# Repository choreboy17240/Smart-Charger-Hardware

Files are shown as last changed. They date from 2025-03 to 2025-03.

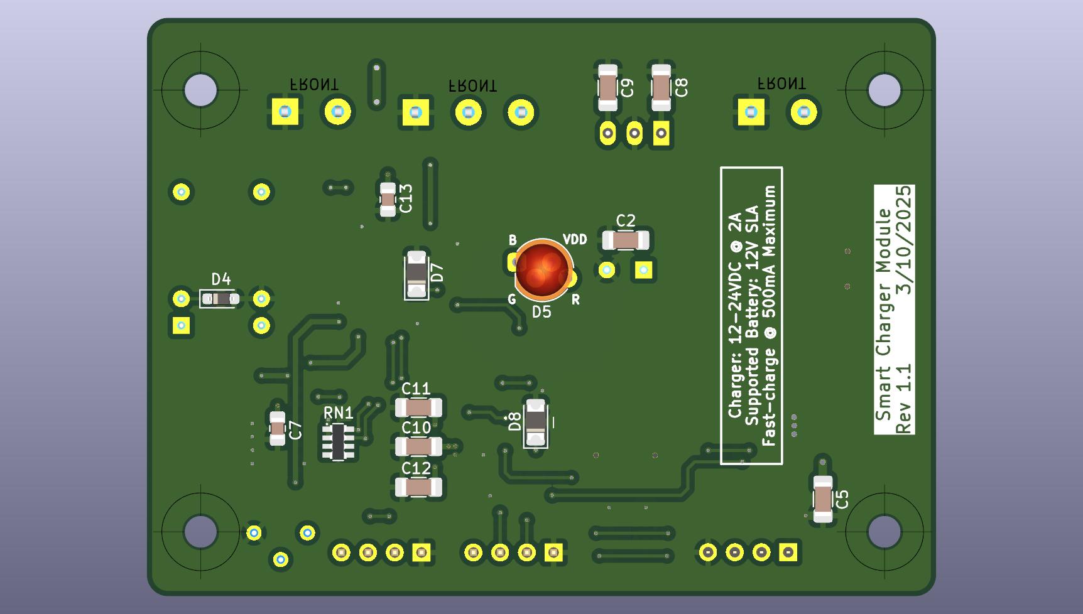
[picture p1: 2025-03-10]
Images/Smart Charger PWB Assembly Bottom v1.1 20250310.jpg

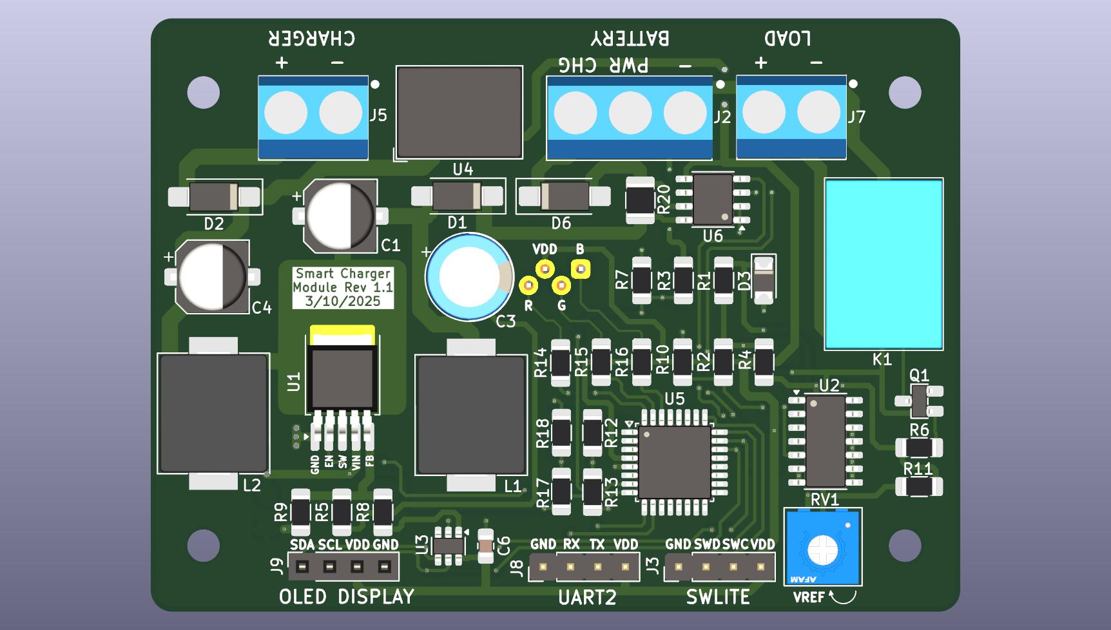
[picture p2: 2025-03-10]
Images/Smart Charger PWB Assembly Top v1.1 20250310.jpg

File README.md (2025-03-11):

# Battery On-Board Charger

## Overview

This repository contains the design files for a Battery On-Board Charger, a DC-DC converter
designed to safely charge sealed lead-acid (SLA) batteries from external power sources. The 
system operates as a buck-boost converter with intelligent microcontroller control for charge
management.

Please see the accompanying software repository on GitHub for an example Arduino STM32 
application that can be built under PlatformIO and used to program the on-board STM32 micro
using an ST-Link programmer.  Programming is done using a custom"SWD-Lite" interface that I 
use for compact, low-cost projects.  SWD-Lite uses a standard 1x4 2.54mm male header to 
provide the absolute minimum number of signals needed or the ST-Link programmer to operate.

I'm sharing this design information and the associated software in hopes that others might 
find it interesting or helpful. It's a hobby project for me, so your mileage may vary!

This is my first attempt to share a KiCad (v9.0) project, so I'd be interested to hear
about whether there are issues or not.  I've exported the global custom symbols and footprints
that I used in the design, so hopefully this should be a standalone PWB design.

## Hardware Specifications

#### Battery Charging
- **Input Voltage**: 12-24V DC
- **Output Voltage**: Adjustable (typically 12V-15.5V for lead-acid batteries)
- **Maximum Charge Current**: 500-600mA
- **Controller**: STM32G030K8T6 (64KB Flash, 8KB RAM)
- **Power Stage**: XL6008 DC-DC converter (Buck-Boost topology)
- **Current Sensing**: INA219 I2C sensor
- **Voltage Control**: MCP4726A0 I2C DAC
- **Status Indicator**: RGB LED
- **Interfaces**: UART, I2C, SWD programming port
- **Operating Temperature**: Room temp

#### Battery Undervoltage Protection 
- **Low-Voltage Cutout**: Adjustable limit (trim pot)

## Key Features

- Software-adjustable charge voltage via I2C DAC
- Real-time current and voltage monitoring
- Temperature-compensated charging profiles
- Multi-stage charging (bulk, absorption, float)
- Status indication via RGB LED
- UART interface for diagnostics and monitoring
- Surge and reverse polarity protection
- Thermal management and over-current protection

## Power Conversion Design

The design utilizes an XL6008 DC-DC converter configured in a buck-boost topology:
- Input filtering through hybrid aluminum capacitors
- High-efficiency power inductors (47µH Sunlord MWSA1004S)
- Schottky diode rectification (B360AE)
- High-quality output filtering with polymer capacitors
- Feedback network with DAC-controlled reference voltage

## PCB Design Considerations

- 2-layer PCB with optimized (kinda) thermal design
- Ground plane for noise reduction and thermal dissipation
- Separate analog and digital ground regions
- Thermal management for XL6008 regulator
- EMI/EMC design practices for switching converter
- Power and signal path optimization

## Undervoltage Protection Circuit

The design incorporates a hardware-based undervoltage protection circuit
to prevent battery damage while under load:

- **Components**:
  - LM339 Quad Comparator for voltage threshold detection
  - MMBT3906 PNP transistor (Q1) for relay driver
  - NS_SRS_SPDT relay (K1) for power disconnection
  - Precision resistor divider network for voltage sensing

- **Operation**:
  - Continuously monitors the battery voltage through a resistive divider
  - When battery voltage falls below a preset threshold (adjustable via the
    RV1 trim pot)
  - Comparator triggers, driving the PNP transistor into conduction
  - Relay energizes, disconnecting the load from the battery
  - Hysteresis provided by R11 (1MΩ) prevents oscillation at threshold
  - D4 provides flyback protection for relay coil

- **Benefits**:
  - Prevents deep discharge of batteries
  - Hardware-based protection operates independently of microcontroller
  - Adjustable threshold for different battery types
  - Fast response time for critical undervoltage conditions
  - Failsafe design ensures load disconnection on power loss

The circuit provides essential protection for battery-powered systems, preventing
damage from excessive discharge while allowing normal operation above the safe 
voltage threshold.

**Note:** As battery voltage limits vary across manufacturers and also depend
on how aggressive you want to be in draining the battery, you will need to 
adjust the RV1 trim potentiometer so that the shutoff occurs at the desired 
voltage. Typical range might be around 11.0-11.5 volts, but check the manufacturer's
recommendation for your battery!

## Thermal Performance

The design has been thermally optimized for enclosed operation:
- Maximum regulator temperature: ~52°C (125°F) at 600mA continuous charging
- Thermal steady state reached after ~30 minutes of operation
- Heat-generating components spaced for optimal thermal dissipation
- Current limited to 600mA for reliability in enclosed environments
- Charging current is constrained by the small heat sink are available for the 
  XL6008 converter, driven by the small packaging space availabe in my project.
- Control software limits the maximum current to that range automatically, but
  this is configurable.
- Redesign the PWB to increase the heat sink area or add a glue-on heat sink
  to the XL6008 if you want higher charging current.

## Usage Notes

See the system connection diagram in the `System` folder for details on how
to connect the module for charging and powering a load from the SLA battery.
The DPDT center-off switch allows the user to select between the following
operating modes:
1. `Charge`: Standby mode with the load off and battery being charged
2. `Power`: Active mode with the load on and charger disconnected
3. `Off`: Shuts down the system completely (no charging, no power to load)

The system should nomrally be left in the `Charge` mode, as the smart charger
is designed to charge up the battery and then automatically shift to a 
standby mode for a software configurable period (default is one week) to 
avoid overcharging the battery.

Charging the battery:
1. Switch the DPDT switch to the `Charge`position
2. The charger automatically determines charge state and applies appropriate charging profile
3. RGB LED color and flashing rate indicates charging status:
   - Blue (fast): Fast bulk charging
   - Yellow (medium): Absorption charging
   - Green (slow): Float/maintenance charging
   - Green (short keep-alive pulse every second): Standby mode
4. Once the battery is charged sufficiently, the charger will enter the standby
   state until it's time to top-off the battery.
   
Using the battery to power a load:
1. Switch the DPDT switch to the `Power` position
2. Battery protection circuit will automatically shut-off the load if battery
   voltage drops below the adjustable threshold.

## Software Configuration

The STM32G030 microcontroller requires appropriate firmware to control the charging process:
- Voltage setpoint control via MCP4726A0 DAC
- Current and voltage monitoring via INA219
- Temperature compensation
- Charging state machine
- Safety monitoring

See the companion firmware repository for microcontroller code.

## Limitations

- Maximum continuous charging current limited to 600mA for thermal management
- Not suitable for high-current applications without additional cooling
- Designed for lead-acid batteries (AGM, Gel, Flooded)
- Requires appropriate firmware for operation

## License

MIT open-source license - see the LICENSE file for details.

## Revision History

- 1.0: Initial design released to JLCPCB for prototype boards
- 1.1: Minor updates for silkscreen fixes

## Contact

Email: choreboy17240@gmail.com

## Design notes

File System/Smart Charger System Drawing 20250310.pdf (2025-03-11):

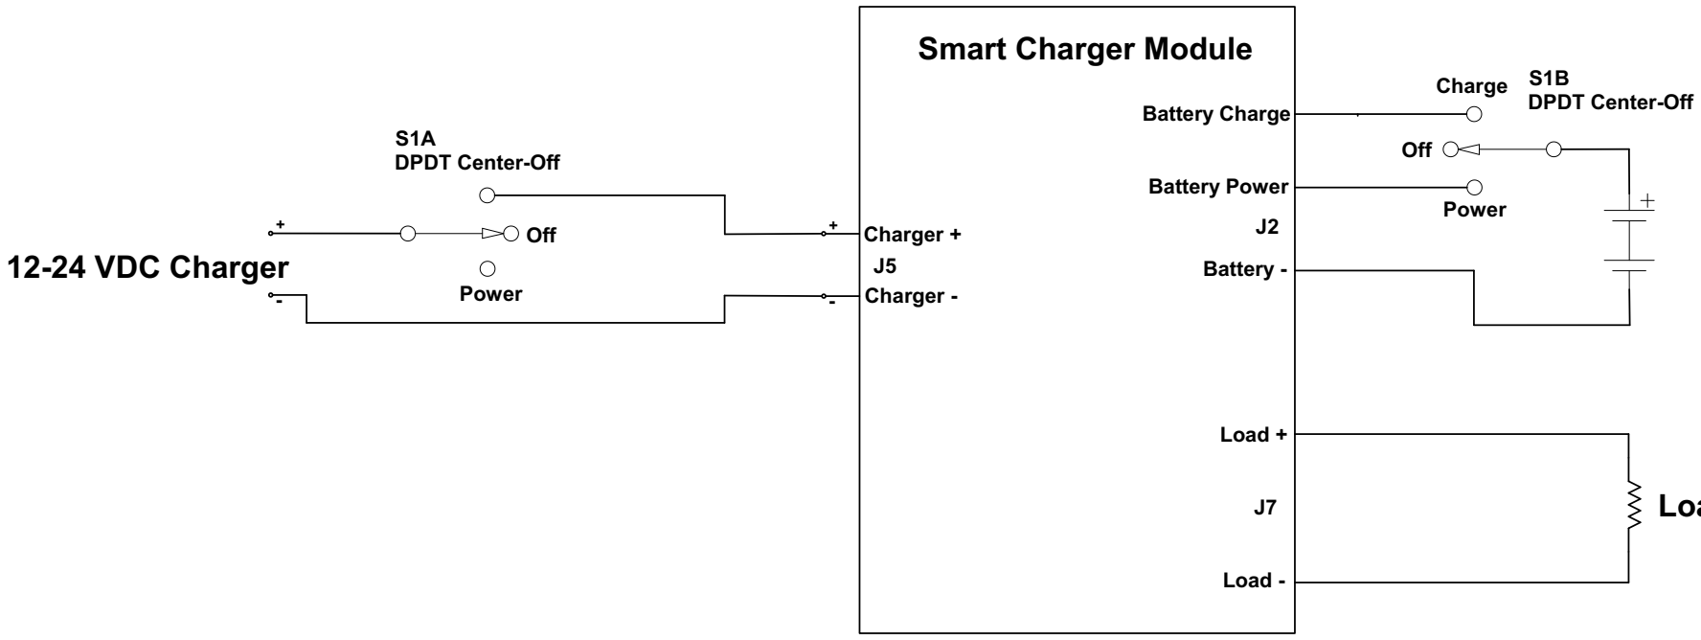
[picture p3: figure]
- - 12-24 VDC Charger; Charger +; Battery Charge; Charger -; Battery Power; Battery -; Load + Load - J7; Smart Charger Module; Charge; Power; Off; S1A DPDT Center-Off; S1B DPDT Center-Off

## Load

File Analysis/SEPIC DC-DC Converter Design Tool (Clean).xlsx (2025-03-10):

SEPIC DC:DC Convertor Design Tool
Design Parameters
VIN (MIN) | 12.0 | Volts
VIN (MAX) | 24.0 | Volts
VOUT (MIN) | 10.0 | Volts
VOUT (MAX) | 15.0 | Volts
VOUT Ripple Voltage | 0.1 | Volts
VD | 0.5 | Volts | B360, 2 Amp, 25C
IOUT (MAX) | 1.0 | Amps
Switching frequency | 400000 | Hz
Cs Value | 22 | uF
1. Duty cycle calculation
Duty cycle (MAX) | 68.9%
Duty cycle (MIN) | 26.6%
2. Inductor selection
L1 Ripple current (worst-case) | 0.5 | Amps
Targeted inductance (L1 = L2) | 4.133333333e-05 | Henry
 | 41.3 | uH
 | 0.04 | mH
L1 peak current | 1.55 | Amps
L2 peak current | 1.20 | Amps
3. Power MOSFET selection
MOSFET peak current | 2.75 | Amps
MOSFET RMS current | 1.72 | Amps
MOSFET voltage (MIN) | 39 | Volts
4. Output Diode Selection
Diode reverse voltage (MIN) | 39.00 | Volts
Diode average current | 1.00 | Amps
5. Coupling Capacitor Selection
Capacitor RMS current | 1.14 | Amps
Capacitor ripple voltage | 0.08 | Volts
6. Output Capacitor Selection
Capacitor RMS current | 1.14 | Amps
ESR (MAX) | 18.2 | mOhms
COUT (MIN) | 34.44444444 | uF
7. Input Capacitor Selection
Capacitor RMS current | 0.14 | Amps

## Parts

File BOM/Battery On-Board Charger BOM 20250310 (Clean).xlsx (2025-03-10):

Battery On-Board Charger Project |  |  |  |  |  |  |  | Revision: 03/10/2025
Reference | Qty | Value | Supplier | Supplier P/N | Manufacturer | Mfr P/N | Description | Comments
C1 | 1 | 22uF/63V | LCSC | C7472372 | NCC | HHXB630ARA220MF80G | Hybrid Al Capacitor SMD D6.3xL7.7mm 22uF 63V 1.5A@100kHz | N/A
C2,C5 | 2 | 1uF/50V | LCSC | C444884 | Samsung | CL31A105KB9LNNC | MLCC Capacitor SMD 1206 1uF 50V X5R | Also available from Digikey
C3 | 1 | 220uF/25V | LCSC | C133440 | NCC | APSG250ELL221MHB5S | Solid Al Capacitor Radial D8xP3.5xL11.5mm 220uF 25V 4.65A@100kHz | N/A
C4 | 1 | 47uF/50V | LCSC | C445256 | Nichicon | UUD1H470MCL1GS | Al Electrolytic Capacitor SMD D6.3xL7.7mm 47uF 50V 230mA@10kHz | N/A
C6,C7,C13 | 3 | 0.1uF/50V | LCSC | C49678 | Yageo | CC0805KRX7R9BB104 | MLCC Capacitor SMD 0805 0.1uF 50V X7R
C8,C9 | 2 | 10uF/50V | LCSC | C89632 | Samsung | CL31B106KBHNNNE | MLCC Capacitor SMD 1206 10uF 50V X7R | Replaces X5R version CL31A106MBHNNNE, also available from Digikey
C10,C12 | 2 | 0.1uF/25V | LCSC | C527347 | Yageo | CC1206KRX7R8BB104 | MLCC Capacitor SMD 1206 0.1uF 25V X7R
C11 | 1 | 4.7uF/50V | LCSC | C51205 | Samsung | CL31B475KBHNNNE | MLCC Capacitor SMD 1206 4.7uF 50V X7R | Also available from Digikey
D1,D2,D6 | 3 | B360AE | LCSC | C412514 | Diodes Inc | B360AE-13 | Schottky Diode SMD SMA 3A 60V Low-Leakage | N/A
D3,D7,D8 | 3 | 3.3V | LCSC | C235771 | On Semi | MMSZ5226BT1G | Diode Zener 3.3V 500mw SOD123
D4 | 1 | 1N4148WS | LCSC | Multiple | Multiple | 1N4148WS | Diode SMD SOD-323 300mA 75V | N/A
D5 | 1 | LED_BGAR | Amazon | N/A | Chanzon | N/A | Chanzon RGB LED THT 5mm BGAR | N/A
J2 | 1 | Tnisesm 01x03 | Stock | N/A | Tnisesm |  | Tnisesm Terminal Block P5mm 1x3 | Amazon
J3 | 1 | SWD_Lite_1x4_Header_THT | Stock |  |  |  | Header Male THT P2.54 1x4P
J5,J7 | 2 | Tnisesm 01x02 | Stock | N/A | Tnisesm |  | Tnisesm Terminal Block P5mm 1x2 | Amazon
J8 | 1 | UART PORT | Stock |  |  |  | Header Male THT P2.54 1x4P
J9 | 1 | OLED DISPLAY | LCSC | C2897367 | HCTL | PM254-1-04-Z-8.5 | Header Female THT P2.54 1x4P
K1 | 1 | NS_SRS_SPDT | LCSC | C32429 | Ningbo Songle | SRS-12VDC-SL | Ningbo Songle Miniature PCB Relay SRS, SPDT, 3A | DIP-12 footprint
L1,L2 | 2 | 47uH | LCSC | C408491 | Sunlord | MWSA1004S-470MT | Power Inductor 47uH 2.8A 147mOhm 10.0x11.5mm SMD | N/A
Q1 | 1 | MMBT3906 | DigiKey |  | Panjit International | MMBT3904_R1_00001 | TRANS PNP 45V 0.8A SOT23
R1,R4 | 2 | 4.7K | Stock |  | Various | TBD | Resistor SMD 1206 | N/A
R2,R3 | 2 | 39K | Stock |  | Various | TBD | Resistor SMD 1206 | N/A
R5,R7,R10,R13 | 4 | 10K | Stock |  | Various | TBD | Resistor SMD 1206 | N/A
R6 | 1 | 470 | Stock |  | Various | TBD | Resistor SMD 1206 | N/A
R8 | 1 | 2.9K | Stock |  | Various | TBD | Resistor SMD 1206 | N/A
R9 | 1 | 1.2K | Stock |  | Various | TBD | Resistor SMD 1206 | N/A
R11 | 1 | 1M | Stock |  | Various | TBD | Resistor SMD 1206 | N/A
R12 | 1 | 1K | Stock |  | Various | TBD | Resistor SMD 1206 | N/A
R14,R15,R16 | 3 | TBD | Stock |  | Various | TBD | Resistor SMD 1206 | N/A
R17 | 1 | 24K | Stock |  | Various | TBD | Resistor SMD 1206 | N/A
R18 | 1 | 3.3K | Stock |  | Various | TBD | Resistor SMD 1206 | N/A
R20 | 1 | 0.1 Ohm | Stock |  | Various | TBD | Resistor SMD 1206/1210 | N/A
RN1 | 1 | 4x10K | LCSC | C110924 | Yageo | YC164-FR-0710KL | Resistor Array SMD 0603x4 10K Isolated | Compatible with CTS 742C083103JP from Digikey.
RV1 | 1 | 20K | Digikey | 3362P-1-223LF-ND | Bourns | 3362P-1-223LF | Trim potentiometer, 22K, 1-turn | "P" footprint vs "H" footprint
U1 | 1 | XL6008 | LCSC | C73012 | XLSEMI | XL6008E1 | 60V 3A Switching Current Boost/Buck_Boost/Inverting DC/DC Converter | N/A
U2 | 1 | LM339 | LCSC | C63821 | On Semi | LM339DR2G | LM339 Quad Comparator SMD SOIC-14
U3 | 1 | MCP4726A0 | LCSC | C191581 | Microchip | MCP4726A0T-E/CH | MCP4726A0 DAC 12-bit I2C interface EEPROM SMD SOT-23-6 | Also available at Digikey
U4 | 1 | R-78E3.3-0.5 | Stock |  |  |  | R-78E3.3-0.5 DC DC Converter 3.3V 2W | RECOM or equivalent
U5 | 1 | STM32G030K8T6 | LCSC | C431631 | ST Micro | STM32G030K8T6 | STM32G030K8T6 64KB Flash 8KB Ram LQFP-32 MCU
U6 | 1 | INA219AIDR | LCSC | C138706 | TI | INA219AIDR | INA219A Current/Power Sensor with I2C SMD SOIC-8

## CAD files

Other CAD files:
System/Smart Charger System Drawing 20250310.dxf

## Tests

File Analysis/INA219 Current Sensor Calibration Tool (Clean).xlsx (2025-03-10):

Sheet: Worksheet
TI INA219 Current Sensor Calibration Calculator
R-shunt | 0.1 | Ohms
V-bus | 32 | Volts
PGA level | /8 | Setting
I-shunt Max Expected | 1.2 | Amps
V-shunt Max | 0.32 | Volts | Determined by PGA level setting
I-shunt Max Possible | 3.2 | Amps | Determined by PGA level setting
LSB Min | 36.6 | uA per bit
LSB Max | 293.0 | uA per bit
LSB Desired | 40.0 | uA per bit
Calibration Value | 10240
Calibration Value (hex) | 0x2800
I-shunt Max w/o Overflow | 3.2 | Amps | May be impacted by LSB and calibration value
V-shunt Max w/o Overflow | 0.32 | Volts | May be impacted by LSB and calibration value
Power Max | 102.4 | Watts | May be impacted by LSB and calibration value

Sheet: Tables
Bus Voltages | PGA Levels | PGA Levels | V-shunt Max
16 | /1 | /1 | 0.040
32 | /2 | /2 | 0.080
 | /4 | /4 | 0.160
 | /8 | /8 | 0.320

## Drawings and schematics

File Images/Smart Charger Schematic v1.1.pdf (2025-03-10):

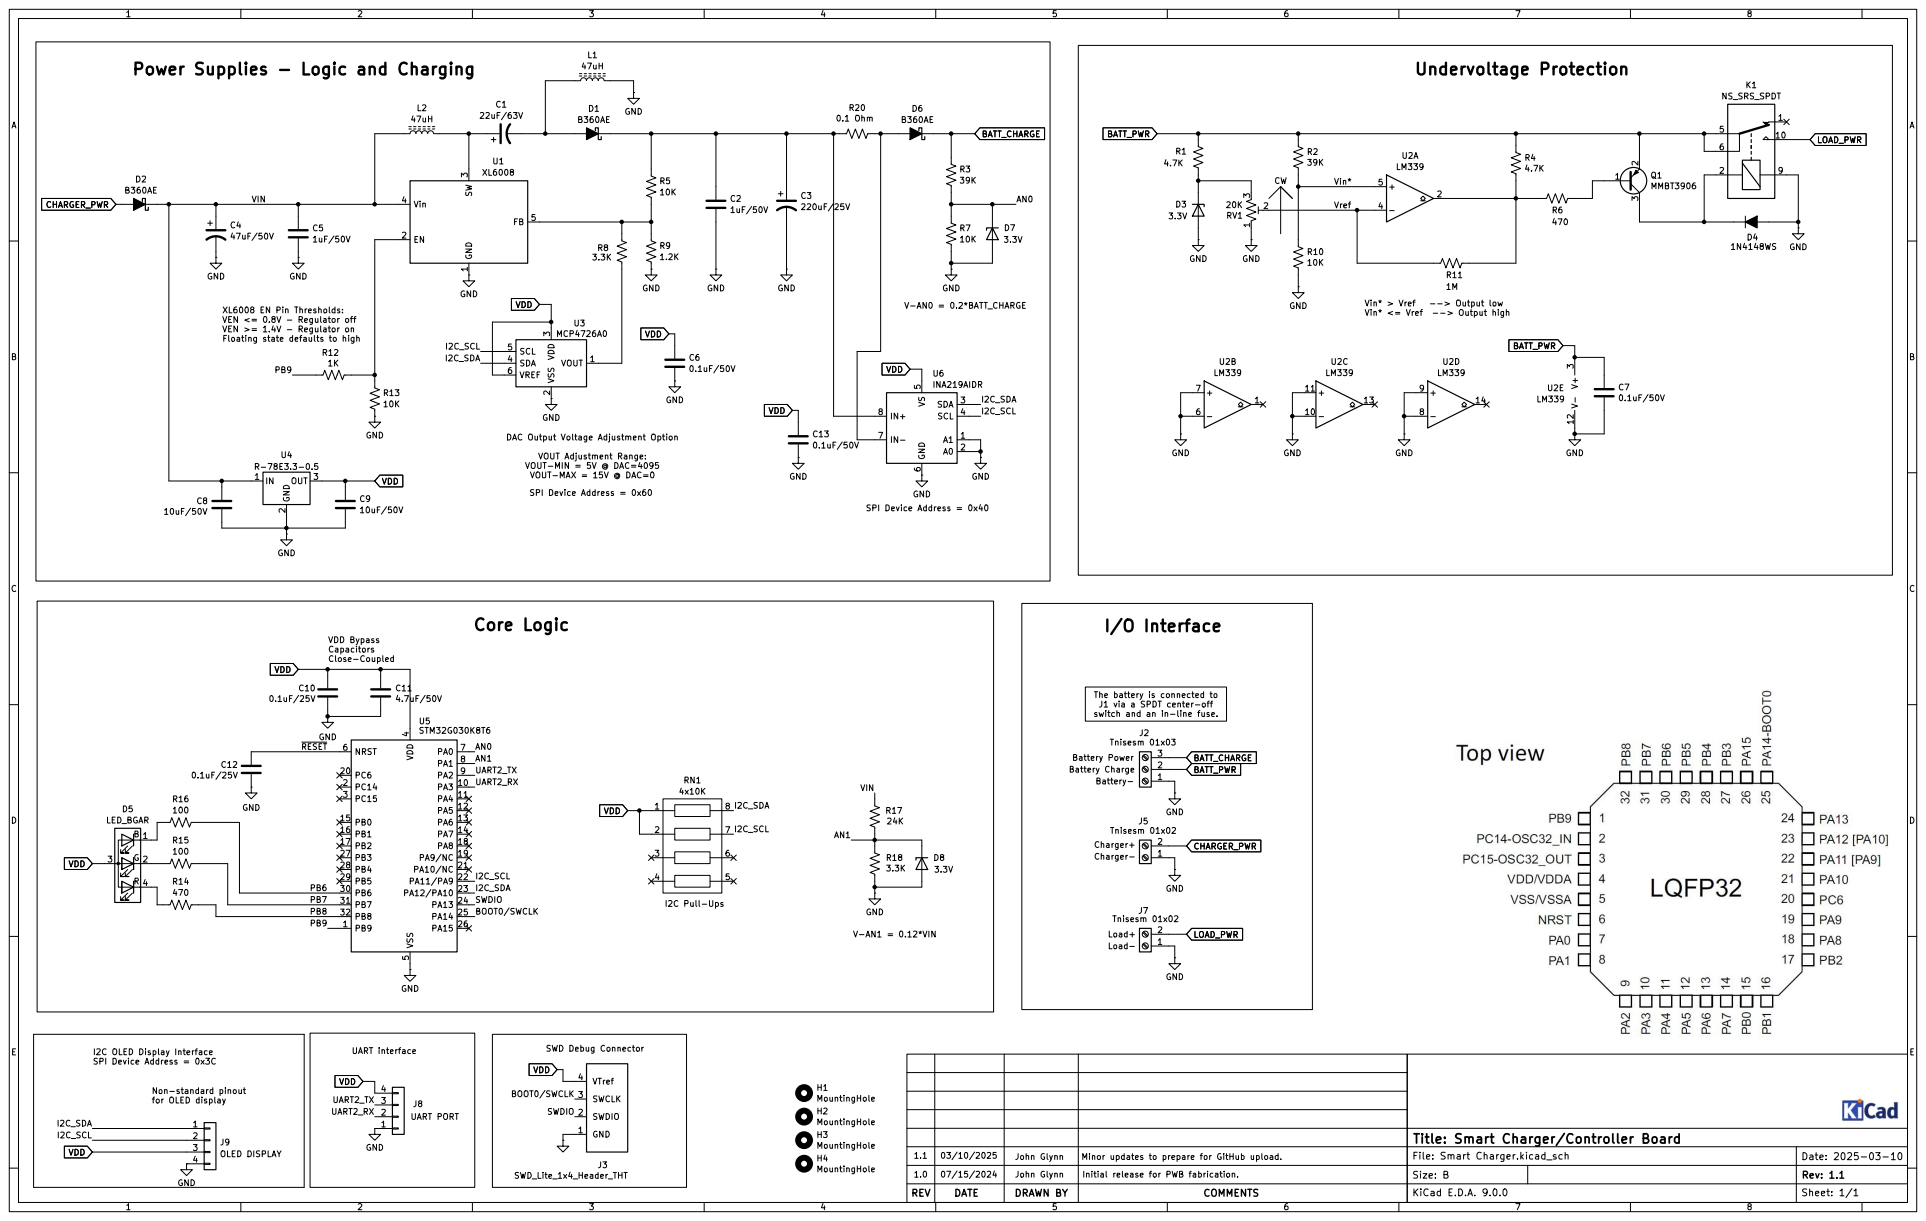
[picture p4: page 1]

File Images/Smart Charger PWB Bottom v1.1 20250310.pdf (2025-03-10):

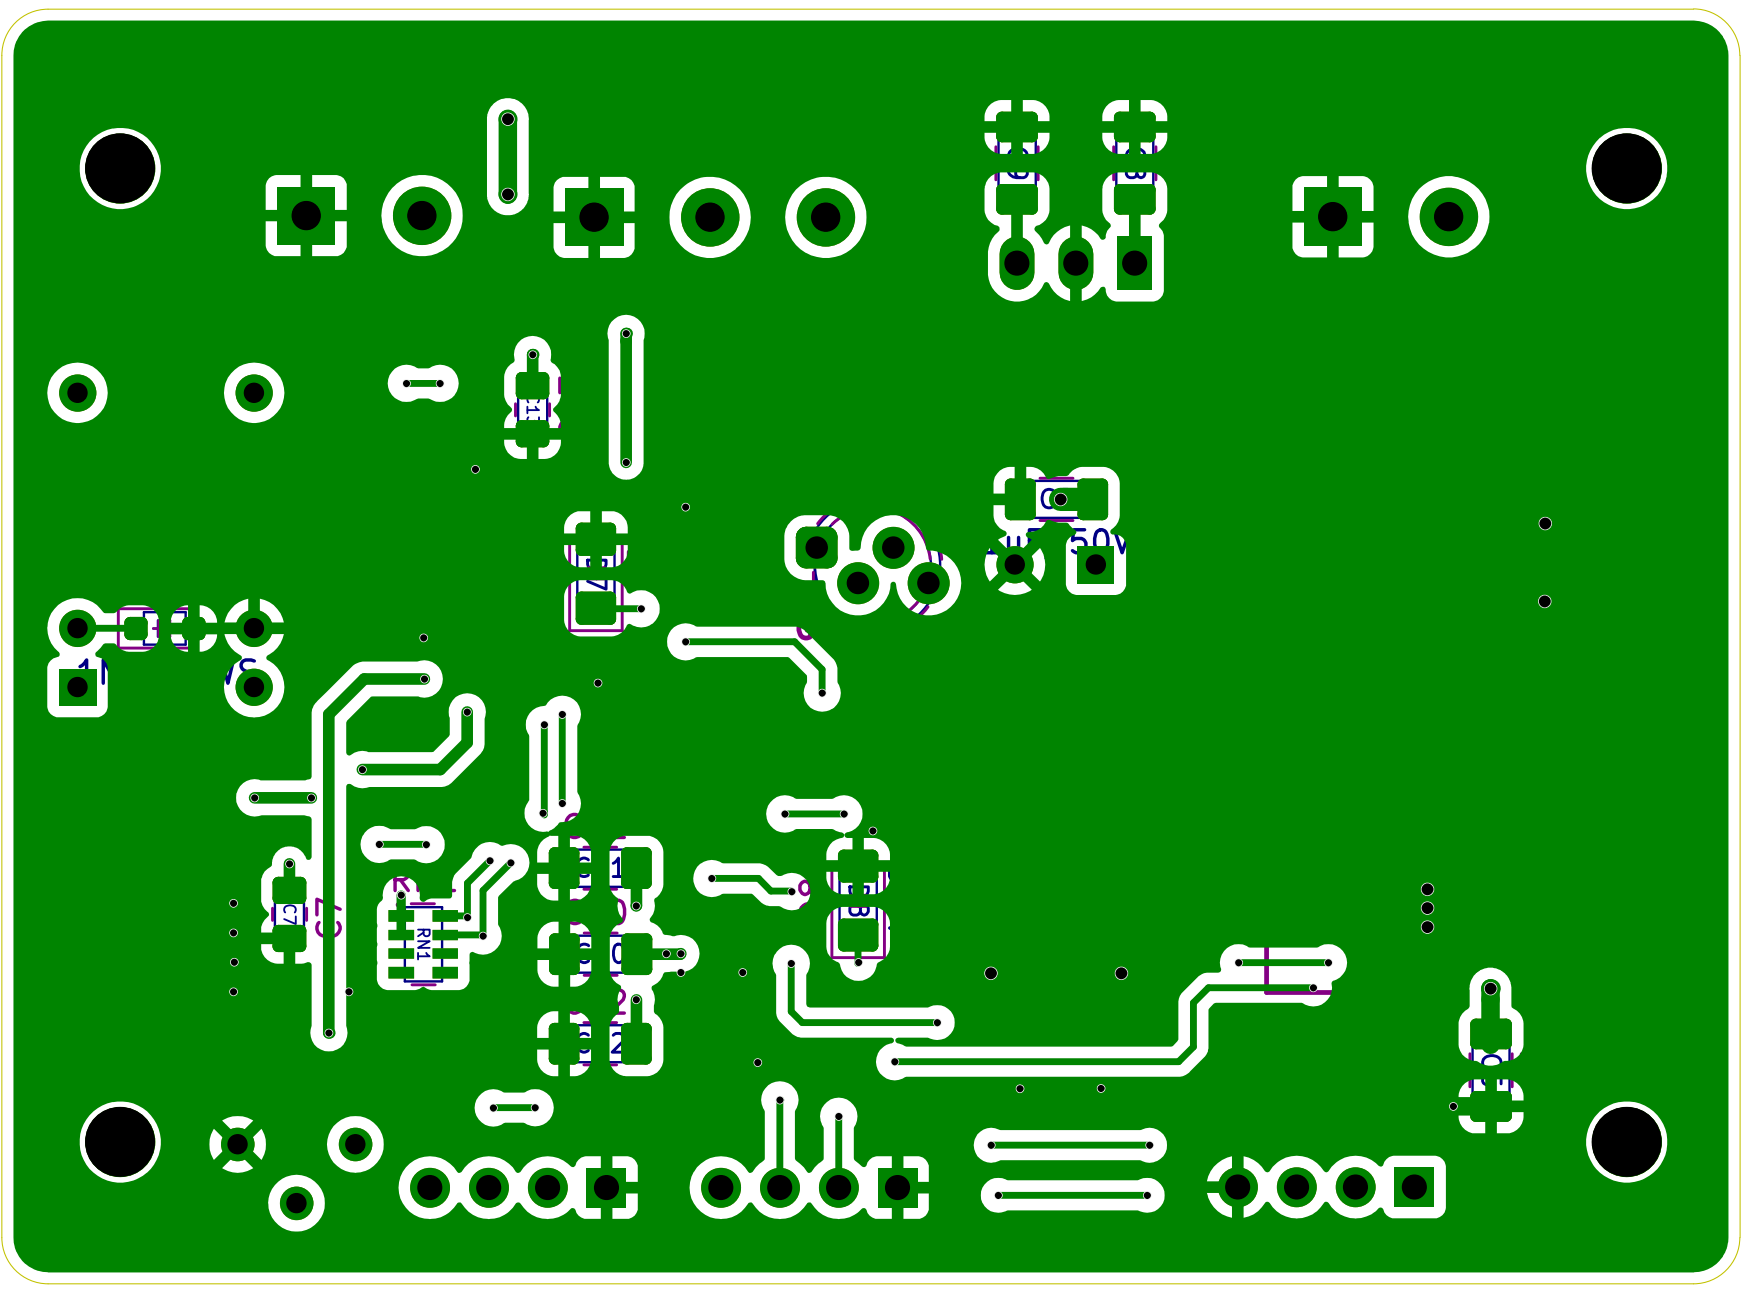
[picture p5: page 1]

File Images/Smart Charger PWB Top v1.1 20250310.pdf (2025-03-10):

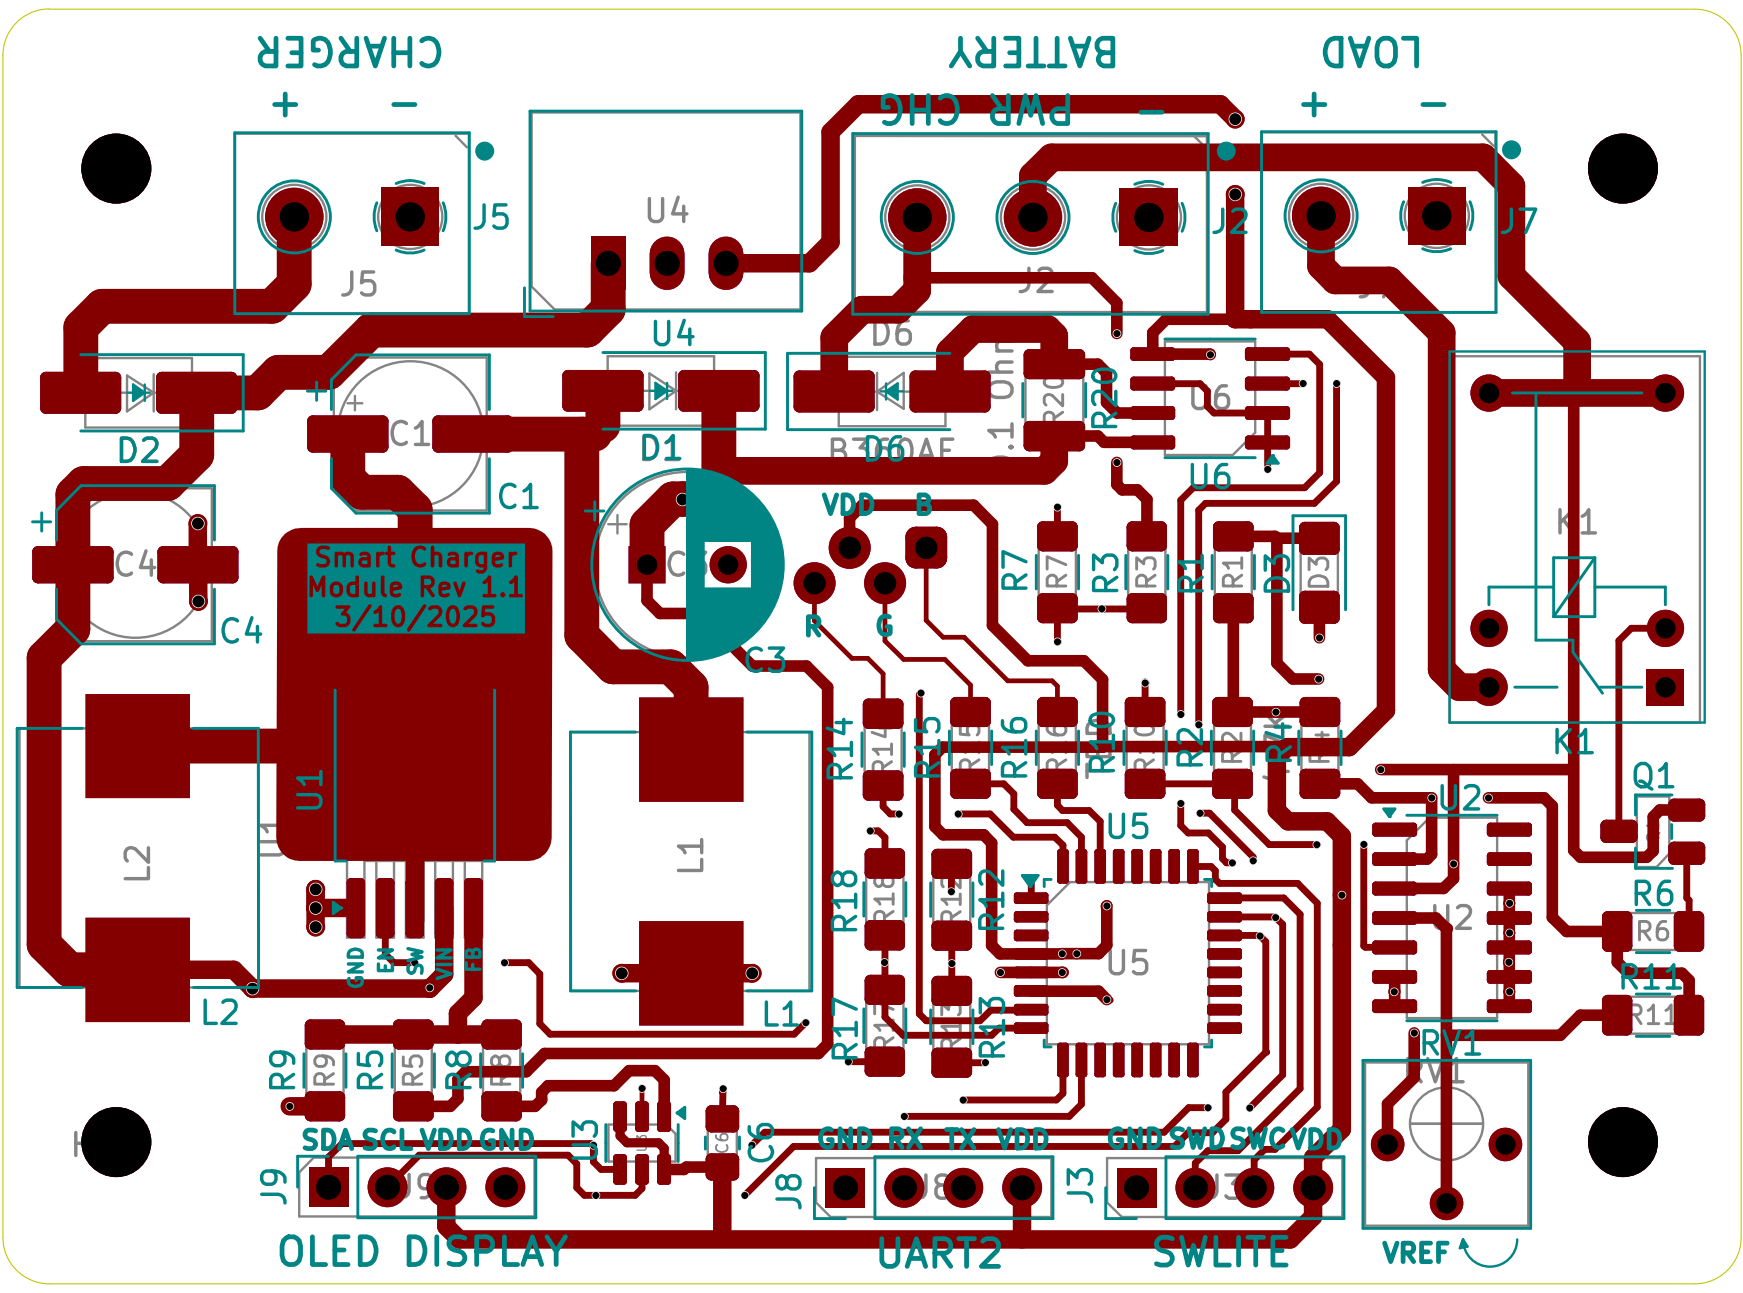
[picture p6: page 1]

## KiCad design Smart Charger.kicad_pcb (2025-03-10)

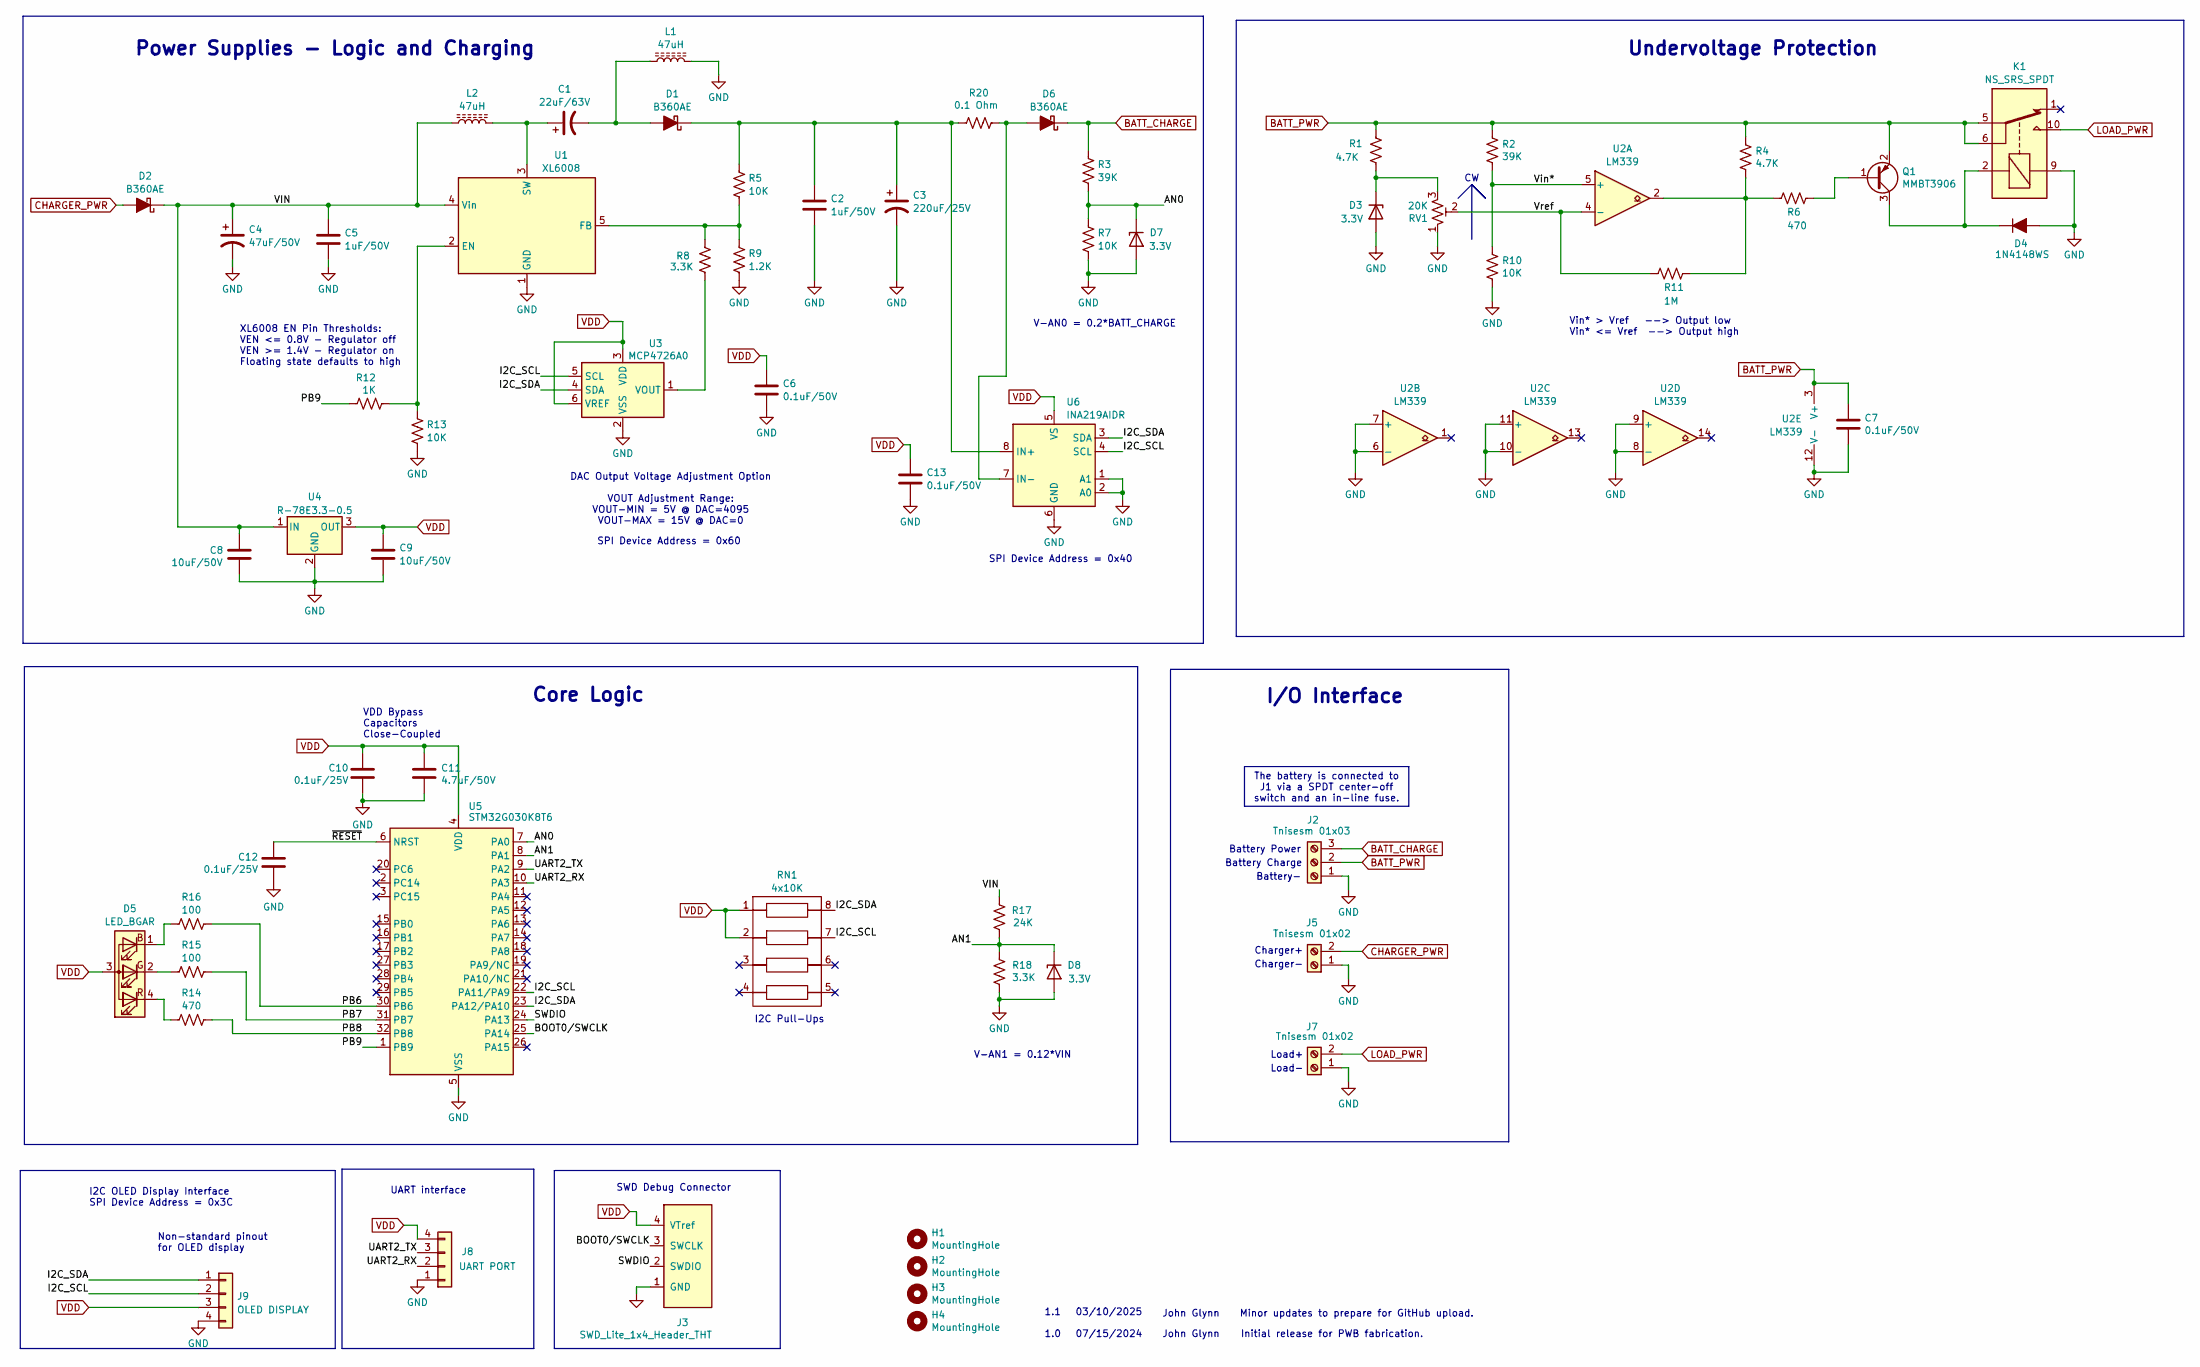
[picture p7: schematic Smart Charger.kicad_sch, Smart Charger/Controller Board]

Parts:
C1: 22uF/63V; CP_Elec_6.3x7.7; Mfr P/N HHXB630ARA220MF80G
C2, C5: 1uF/50V; C_1206_3216Metric_Pad1.33x1.80mm_HandSolder; Mfr P/N CL31A105KB9LNNC
C3: 220uF/25V; CP_Radial_D8.0mm_P3.50mm; Mfr P/N APSG250ELL221MHB5S
C4: 47uF/50V; CP_Elec_6.3x7.7; Mfr P/N UUD1H470MCL1GS
C6, C7, C13: 0.1uF/50V; C_0805_2012Metric_Pad1.18x1.45mm_HandSolder; Mfr P/N CC0805KRX7R9BB104
C8, C9: 10uF/50V; C_1206_3216Metric_Pad1.33x1.80mm_HandSolder; Mfr P/N CL31B106KBHNNNE
C10, C12: 0.1uF/25V; C_1206_3216Metric_Pad1.33x1.80mm_HandSolder; Mfr P/N CC1206KRX7R8BB104
C11: 4.7uF/50V; C_1206_3216Metric_Pad1.33x1.80mm_HandSolder; Mfr P/N CL31B475KBHNNNE
D1, D2, D6: B360AE; D_SMA_Handsoldering; Mfr P/N B360AE-13
D3, D7, D8: 3.3V; D_1206_3216Metric_Pad1.42x1.75mm_HandSolder; Mfr P/N MMSZ5226BT1G
D4: 1N4148WS; D_SOD-323_HandSoldering; Mfr P/N 1N4148WS
D5: LED_BGAR; LED_D5.0mm-4_RGB_Staggered_Pins; Mfr P/N N/A
H1, H2, H3, H4: MountingHole; MountingHole_#4-40_Screw
J2: Tnisesm 01x03; TerminalBlock_Tnisesm_Screw_1x03_P5.00mm
J3: SWD_Lite_1x4_Header_THT; PinHeader_1x04_P2.54mm_Vertical
J5, J7: Tnisesm 01x02; TerminalBlock_Tnisesm_Screw_1x02_P5.00mm
J8: UART PORT; PinHeader_1x04_P2.54mm_Vertical
J9: OLED DISPLAY; PinSocket_1x04_P2.54mm_Vertical; Mfr P/N PM254-1-04-Z-8.5
K1: NS_SRS_SPDT; Relay_SPDT_Songle_Miniature_SRS; Mfr P/N SRS-xxVDC-SL
L1, L2: 47uH; L_SMD_Sunlord_MWSA1004S_10.0x11.5mm; Mfr P/N MWSA1004S-470MT
Q1: MMBT3906; SOT-23_Handsolder_Large_Pads; Mfr P/N MMBT3904_R1_00001
R1, R4: 4.7K; R_1206_3216Metric_Pad1.30x1.75mm_HandSolder; Mfr P/N TBD
R2, R3: 39K; R_1206_3216Metric_Pad1.30x1.75mm_HandSolder; Mfr P/N TBD
R5, R7, R10, R13: 10K; R_1206_3216Metric_Pad1.30x1.75mm_HandSolder; Mfr P/N TBD
R6, R14: 470; R_1206_3216Metric_Pad1.30x1.75mm_HandSolder; Mfr P/N TBD
R8, R18: 3.3K; R_1206_3216Metric_Pad1.30x1.75mm_HandSolder; Mfr P/N TBD
R9: 1.2K; R_1206_3216Metric_Pad1.30x1.75mm_HandSolder; Mfr P/N TBD
R11: 1M; R_1206_3216Metric_Pad1.30x1.75mm_HandSolder; Mfr P/N TBD
R12: 1K; R_1206_3216Metric_Pad1.30x1.75mm_HandSolder; Mfr P/N TBD
R15, R16: 100; R_1206_3216Metric_Pad1.30x1.75mm_HandSolder; Mfr P/N TBD
R17: 24K; R_1206_3216Metric_Pad1.30x1.75mm_HandSolder; Mfr P/N TBD
R20: 0.1 Ohm; R_1210_3225Metric_Pad1.30x2.65mm_HandSolder; Mfr P/N TBD
RN1: 4x10K; RN_Array_4x0603; Mfr P/N YC164-FR-0710KL
RV1: 20K; Potentiometer_Bourns_3362P_Vertical; Mfr P/N 3362P-1-223LF
U1: XL6008; TO-252-5L_TabPin3_Hand_Solder; Mfr P/N XL6008E1
U2: LM339; SOIC-14_3.9x8.7mm_P1.27mm; Mfr P/N LM339DR2G
U3: MCP4726A0; SOT-23-6; Mfr P/N MCP4726A0T-E/CH
U4: R-78E3.3-0.5; Converter_DCDC_RECOM_R-78E-0.5_THT
U5: STM32G030K8T6; LQFP-32_7x7mm_P0.8mm; Mfr P/N STM32G030K8T6
U6: INA219AIDR; SOIC-8_3.9x4.9mm_P1.27mm; Mfr P/N INA219AIDR

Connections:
/AN0: D7.1 (K), R3.2, R7.1, U5.7 (PA0)
/AN1: D8.1 (K), R17.2, R18.1, U5.8 (PA1)
/BOOT0/SWCLK: J3.3 (SWCLK), U5.25 (PA14)
/I2C_SCL: J9.2, RN1.7 (R2B), U3.5 (SCL), U5.22 (PA11/PA9), U6.4 (SCL)
/I2C_SDA: J9.1, RN1.8 (R1B), U3.4 (SDA), U5.23 (PA12/PA10), U6.3 (SDA)
/PB6: R16.1, U5.30 (PB6)
/PB7: R15.1, U5.31 (PB7)
/PB8: R14.1, U5.32 (PB8)
/PB9: R12.2, U5.1 (PB9)
/SWDIO: J3.2 (SWDIO), U5.24 (PA13)
/UART2_RX: J8.2, U5.10 (PA3)
/UART2_TX: J8.3, U5.9 (PA2)
/VIN: C4.1, C5.2, C8.1, D2.1 (K), L2.1, R17.1, U1.4 (Vin), U4.1 (IN)
/Vin*: R2.2, R10.1, U2.5 (+)
/Vref: R11.2, RV1.2, U2.4 (-)
/~RESET: C12.1, U5.6 (NRST)
BATT_CHARGE: D6.1 (K), J2.3, R3.1
BATT_PWR: C7.1, J2.2, K1.5, K1.6, Q1.2 (E), R1.1, R2.1, R4.1, U2.3 (V+)
CHARGER_PWR: D2.2 (A), J5.2
GND: C2.1, C3.2, C4.2, C5.1, C6.2, C7.2, C8.2, C9.2, C10.2, C11.2, C12.2, C13.2, D3.2 (A), D4.2 (A), D7.2 (A), D8.2 (A), J2.1, J3.1 (GND), J5.1, J7.1, J8.1, J9.4, K1.9, L1.2, R7.2, R9.2, R10.2, R13.2, R18.2, RV1.1, U1.1 (GND), U2.6 (-), U2.7 (+), U2.8 (-), U2.9 (+), U2.10 (-), U2.11 (+), U2.12 (V-), U3.2 (VSS), U4.2 (GND), U5.5 (VSS), U6.1 (A1), U6.2 (A0), U6.6 (GND)
LOAD_PWR: J7.2, K1.10
unnamed: C1.2, D1.2 (A), L1.1
unnamed: C2.2, C3.1, D1.1 (K), R5.1, R20.2, U6.8 (IN+)
unnamed: D3.1 (K), R1.2, RV1.3
unnamed: D4.1 (K), K1.2, Q1.3 (C)
unnamed: D5.1 (BK), R16.2
unnamed: D5.2 (GK), R15.2
unnamed: D5.4 (RK), R14.2
unnamed: D6.2 (A), R20.1, U6.7 (IN-)
unnamed: Q1.1 (B), R6.1
unnamed: R4.2, R6.2, R11.1, U2.2
unnamed: R12.1, R13.1, U1.2 (EN)
unnamed: R5.2, R8.2, R9.1, U1.5 (FB)
unnamed: C1.1, L2.2, U1.3 (SW)
unnamed: R8.1, U3.1 (VOUT)
VDD: C6.1, C9.1, C10.1, C11.1, C13.1, D5.3 (A), J3.4 (VTref), J8.4, J9.3, RN1.1 (R1A), RN1.2 (R2A), U3.3 (VDD), U3.6 (VREF), U4.3 (OUT), U5.4 (VDD), U6.5 (VS)

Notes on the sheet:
Battery Charge
Battery-
I/O Interface
DAC Output Voltage Adjustment Option VOUT Adjustment Range: VOUT-MIN = 5V @ DAC=4095 VOUT-MAX = 15V @ DAC=0
Battery Power
I2C Pull-Ups
VDD Bypass Capacitors Close-Coupled
Initial release for PWB fabrication.
Minor updates to prepare for GitHub upload.
Charger+
1.0
Power Supplies - Logic and Charging
Non-standard pinout for OLED display
I2C OLED Display Interface SPI Device Address = 0x3C
Load+
SPI Device Address = 0x60
John Glynn
Vin* > Vref --> Output low Vin* <= Vref --> Output high
XL6008 EN Pin Thresholds: VEN <= 0.8V - Regulator off VEN >= 1.4V - Regulator on Floating state defaults to high
03/10/2025
Load-
V-AN1 = 0.12*VIN
UART interface
V-AN0 = 0.2*BATT_CHARGE
Undervoltage Protection
Core Logic
1.1
07/15/2024
Charger-
SPI Device Address = 0x40
SWD Debug Connector
The battery is connected to J1 via a SPDT center-off switch and an in-line fuse.

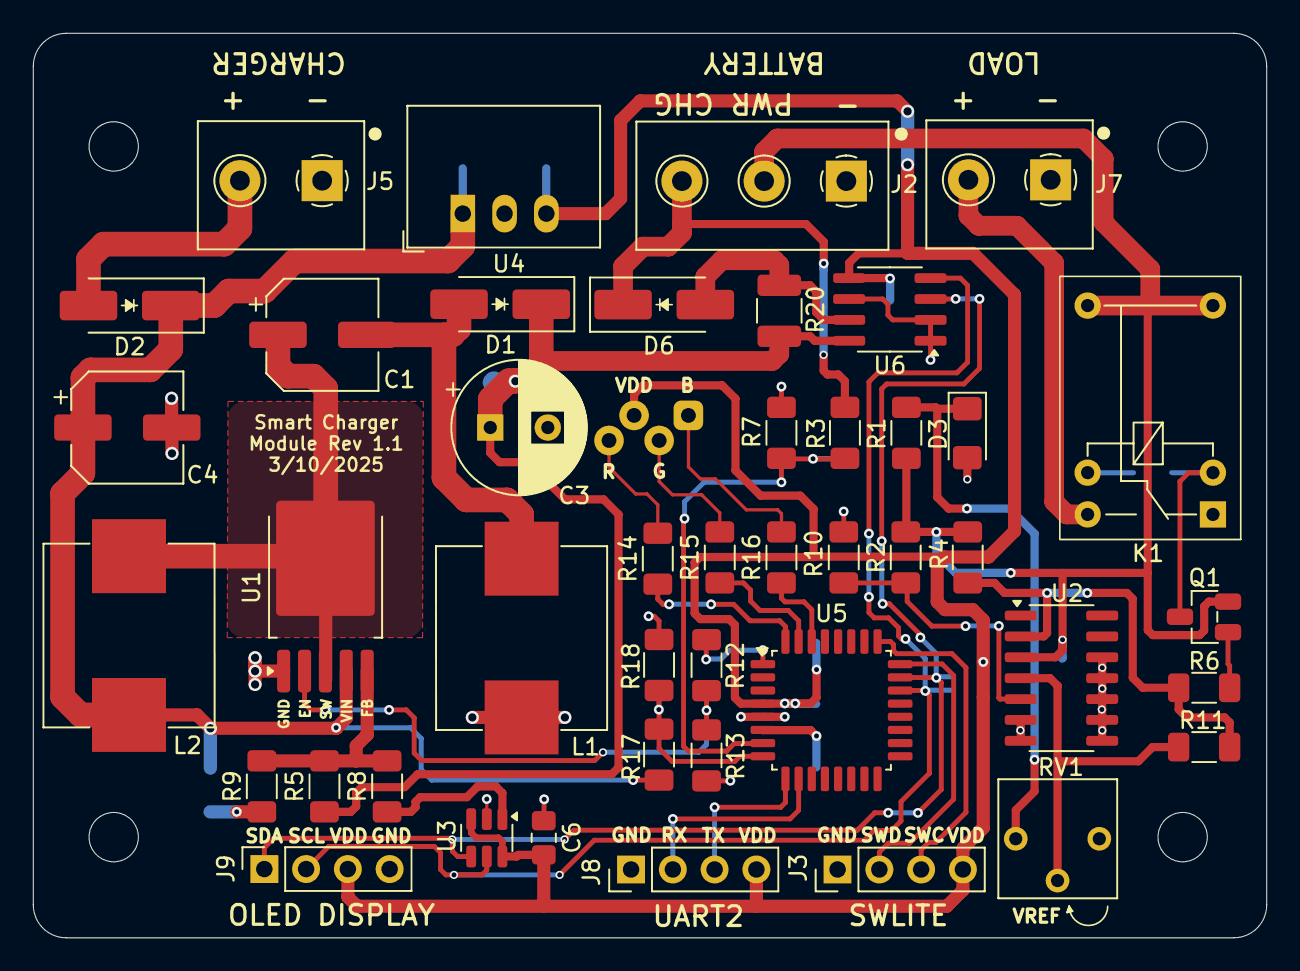
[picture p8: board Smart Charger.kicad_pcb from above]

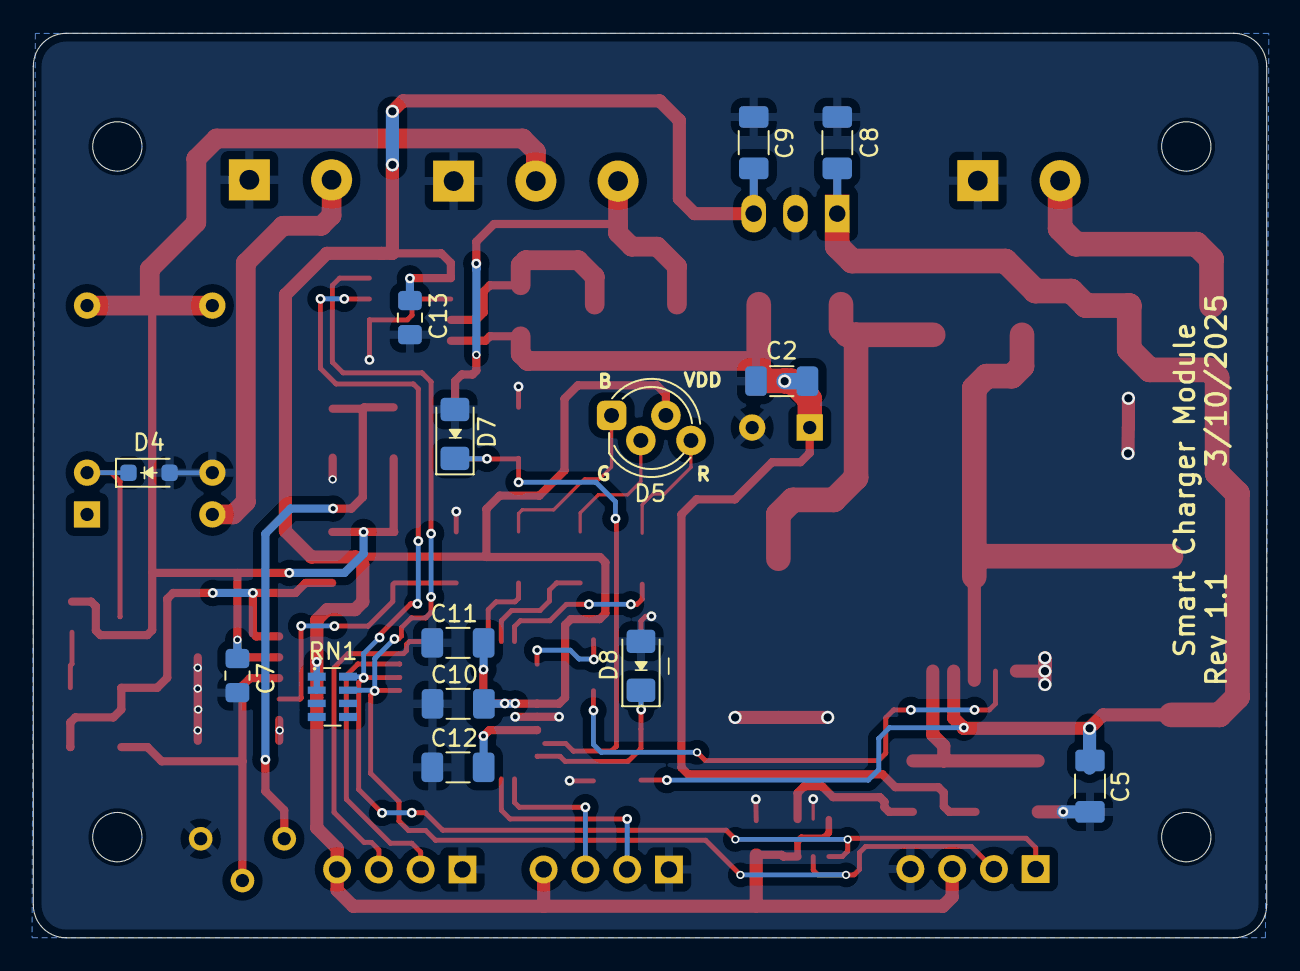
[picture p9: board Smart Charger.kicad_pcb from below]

Board: 2 copper layers, 75.0 x 55.0 mm, 62 parts (14 on the bottom side), 36 nets.

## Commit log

2025-03-10 v1.1 release for upload to GitHub
    [Battery On-Board Charger BOM 20250310 (Clean).xlsx, INA219 Current Sensor Calibration Tool (Clean).xlsx, SEPIC DC-DC Converter Design Tool (Clean).xlsx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]
2025-03-11 Added system connection drawing and updated README.md file with system information.
    [Smart Charger System Drawing 20250310.dxf]
